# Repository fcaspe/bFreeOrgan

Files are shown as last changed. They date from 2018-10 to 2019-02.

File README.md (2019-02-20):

# bFreeOrgan
### A free Organ Synthesizer based on STM32F4.
**by Franco Caspe**

bFreeOrgan is an open source plattform for Additive Synthesis based on the well-regarded and low-cost Cortex M4 Microcontroller.
As of today, the plattform is used to implement a Synchronous Drawbar Organ Synthesizer that works with the STM32F407 Discovery board.
This project started in 2017, coded in C with ST Microelectronics Standard Peripheral Driver.

### Project state
This project is now IDE agnostic! Is built now with GNU make and arm gcc toolset.

[ARM GCC Toolset website](https://developer.arm.com/open-source/gnu-toolchain/gnu-rm/downloads)

For Flashing the discovery, the makefile uses texane/stlink tool. The latest version that is currently working fine for the STM32F4 Discovery board is 1.3.0.

[Texane's stlink utility](https://github.com/texane/stlink)

This repo currently contains the source and System Workbench project, KiCad project for the Main PCB and some calibration utils.
You can fancy your own drawbar controller (SEE PDF). 
3D Print Case is still pending! But, with a little creativity this project can be built! (see images)

### Building
Just make sure the arm-gcc toolset path is set in the PATH bash's enviroment variable when you run make.

1. Run: make
2. Connect the STM32F4 Discovery Board to the PC.
3. Run: make flash

### See it working!

[bFreeOrgan Prototype No.1](https://www.youtube.com/watch?v=Aql0KdO9ymM&t=1s)
### Some Images

Last Version PCB!
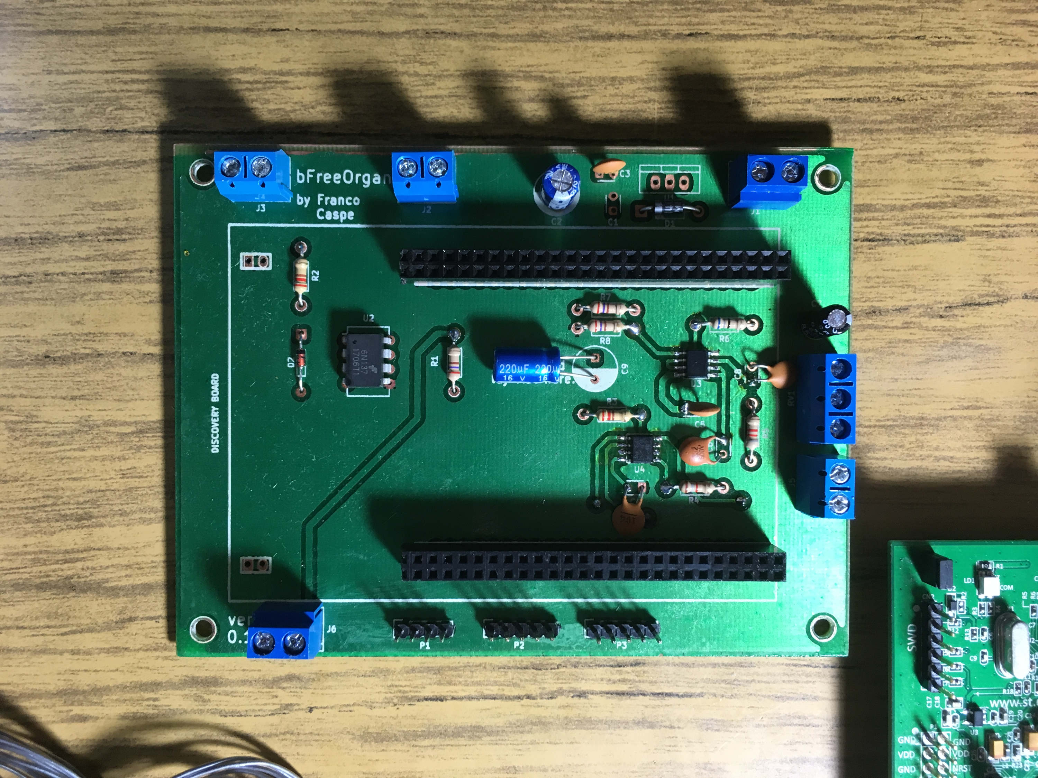
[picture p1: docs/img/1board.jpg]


bFreeOrgan PCB with Discovery board mounted on.
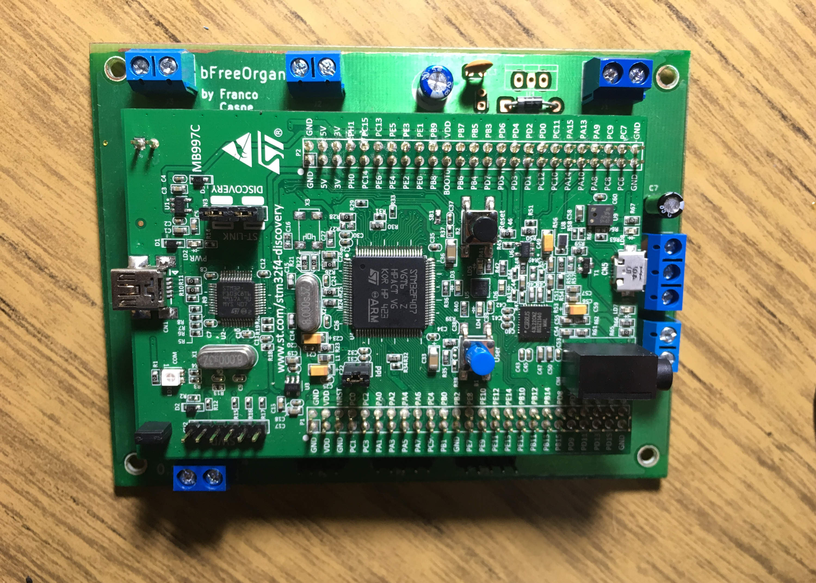
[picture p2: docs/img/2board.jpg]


Front Prototype Case
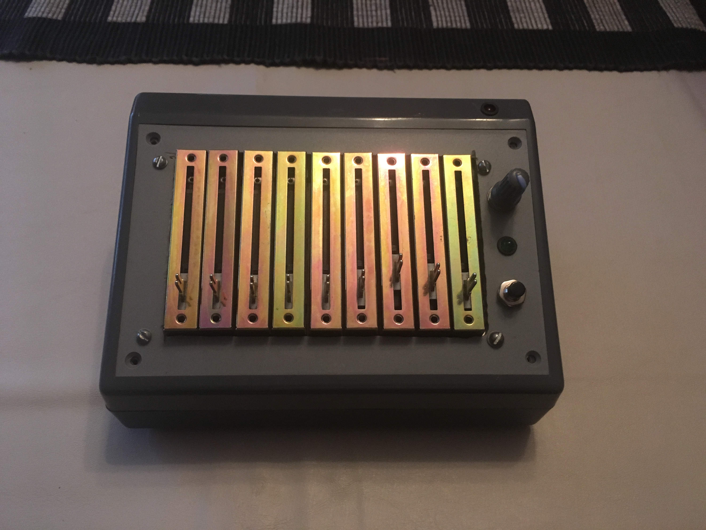
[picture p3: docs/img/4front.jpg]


Rear Prototype Case
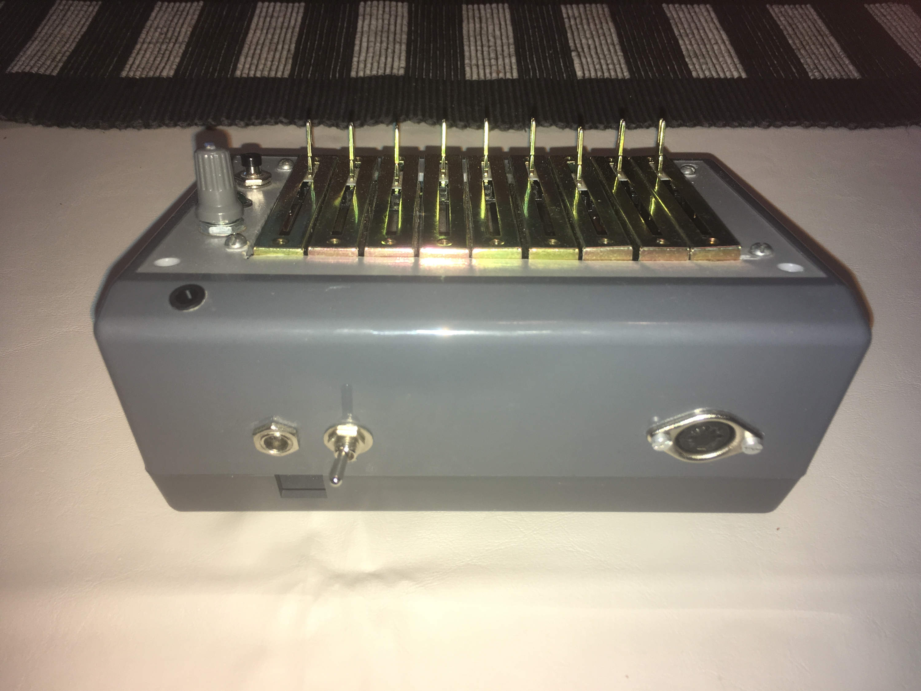
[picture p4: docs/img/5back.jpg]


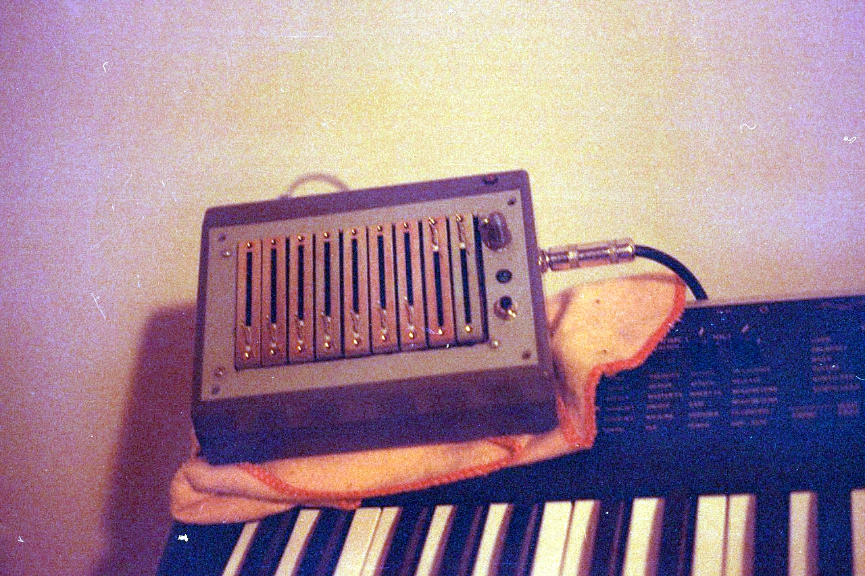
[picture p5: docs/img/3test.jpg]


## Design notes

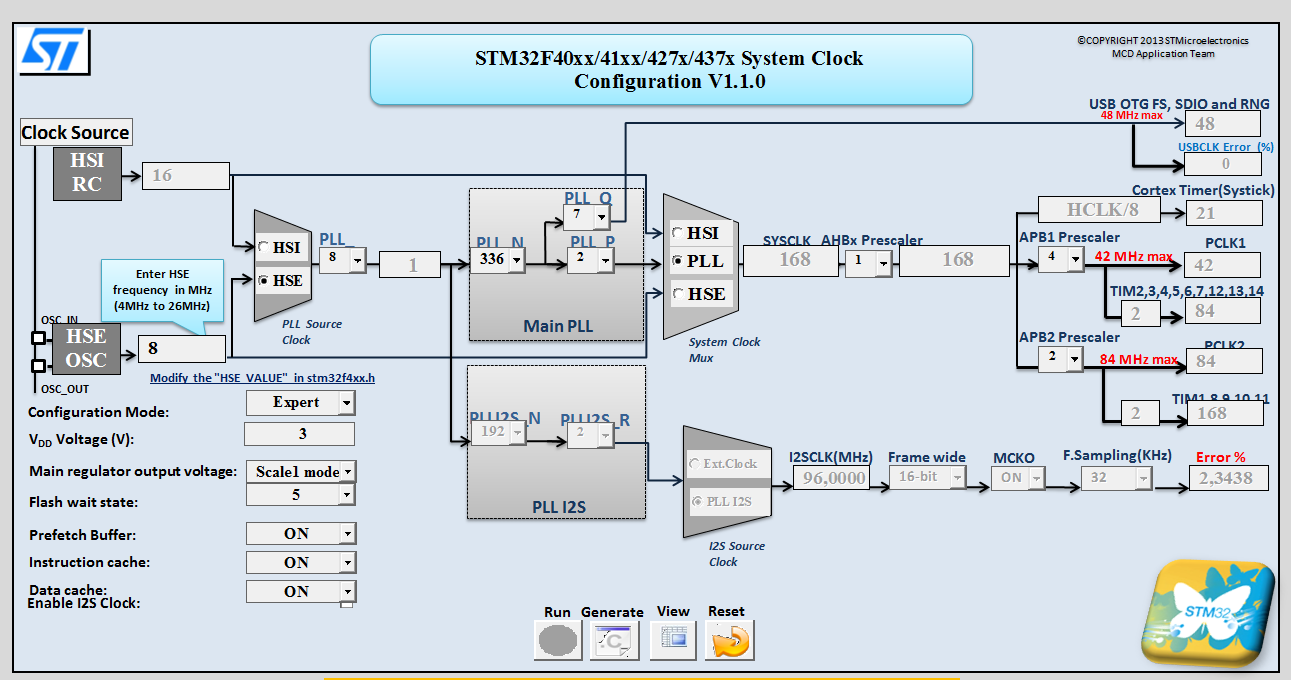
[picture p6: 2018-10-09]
src/src/clock_config.png

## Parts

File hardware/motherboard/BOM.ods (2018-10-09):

Reference | Value | Footprint | Datasheet
JDISCOVERY1 | STM32F4_Discovery_Header | w_conn_misc:stm32f4_discovery_header
J1 | Screw_Terminal_1x02 | Connectors:bornier2
J3 | Screw_Terminal_1x02 | Connectors:bornier2
J2 | 5V Auxiliar | Connectors:bornier2
J5 | Screw_Terminal_1x02 | Connectors:bornier2
J6 | Drawbar Board +3V | Connectors:bornier2
RV1 | 10k | Connectors:bornier3
U1 | 7805 | TO_SOT_Packages_THT:TO-220_Neutral123_Vertical
U2 | 6N137 | Housings_DIP:DIP-8_W7.62mm
U4 | MAX5541 | SMD_Packages:SOIC-8-N
U3 | MC33202 | SMD_Packages:SOIC-8-N
D1 | 1N4007 | Diodes_THT:Diode_DO-41_SOD81_Horizontal_RM10
D2 | 1N4148 | Diodes_THT:Diode_DO-35_SOD27_Horizontal_RM10
R2 | 220 | Resistors_THT:Resistor_Horizontal_RM10mm
R1 | 270 | Resistors_THT:Resistor_Horizontal_RM10mm
R3 | 220 | Resistors_THT:Resistor_Horizontal_RM10mm
R4 | 1.8k | Resistors_THT:Resistor_Horizontal_RM10mm
R5 | 8.2k | Resistors_THT:Resistor_Horizontal_RM10mm
R6 | 68 | Resistors_THT:Resistor_Horizontal_RM10mm
R7 | 270 | Resistors_THT:Resistor_Horizontal_RM10mm
R8 | 270 | Resistors_THT:Resistor_Horizontal_RM10mm
C1 | 330nF | Capacitors_THT:C_Disc_D3_P2.5
C2 | 220uF | Capacitors_THT:C_Radial_D8_L21_P3.8
C6 | 3.3nF | Capacitors_THT:C_Disc_D3_P2.5
C8 | 1nF | Capacitors_THT:C_Disc_D3_P2.5
C3 | 100nF | Capacitors_THT:C_Disc_D3_P2.5
C5 | 100nF | Capacitors_THT:C_Disc_D3_P2.5
C7 | 22uF | Capacitors_THT:C_Radial_D5_L11_P2.5
C4 | 100nF | Capacitors_THT:C_Disc_D3_P2.5
C9 | 220uF | Capacitors_THT:C_Radial_D8_L21_P3.8
P3 | CONN_01X05 | Pin_Headers:Pin_Header_Straight_1x05
P2 | CONN_01X05 | Pin_Headers:Pin_Header_Straight_1x05
P1 | CONN_01X04 | Pin_Headers:Pin_Header_Straight_1x04

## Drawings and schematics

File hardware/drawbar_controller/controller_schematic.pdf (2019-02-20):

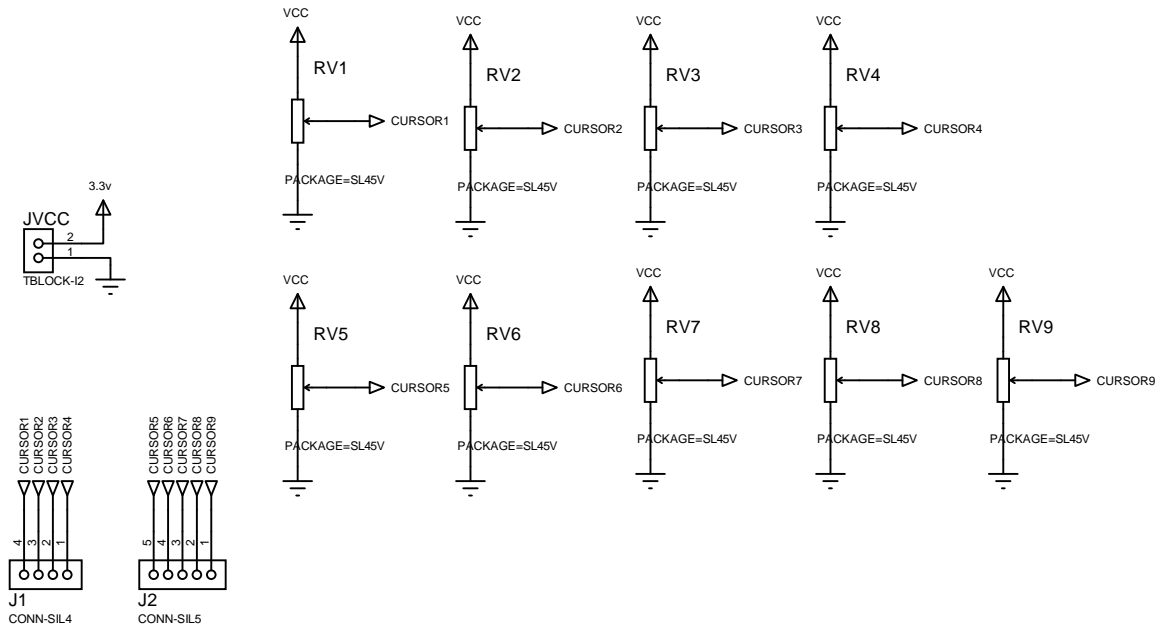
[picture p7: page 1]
PACKAGE=SL45V; VCC; CURSOR1; CURSOR2; CURSOR3; CURSOR4; CURSOR5; CURSOR6; CURSOR7; CURSOR8; CURSOR9; CONN-SIL4; CONN-SIL5; JVCC; TBLOCK-I2

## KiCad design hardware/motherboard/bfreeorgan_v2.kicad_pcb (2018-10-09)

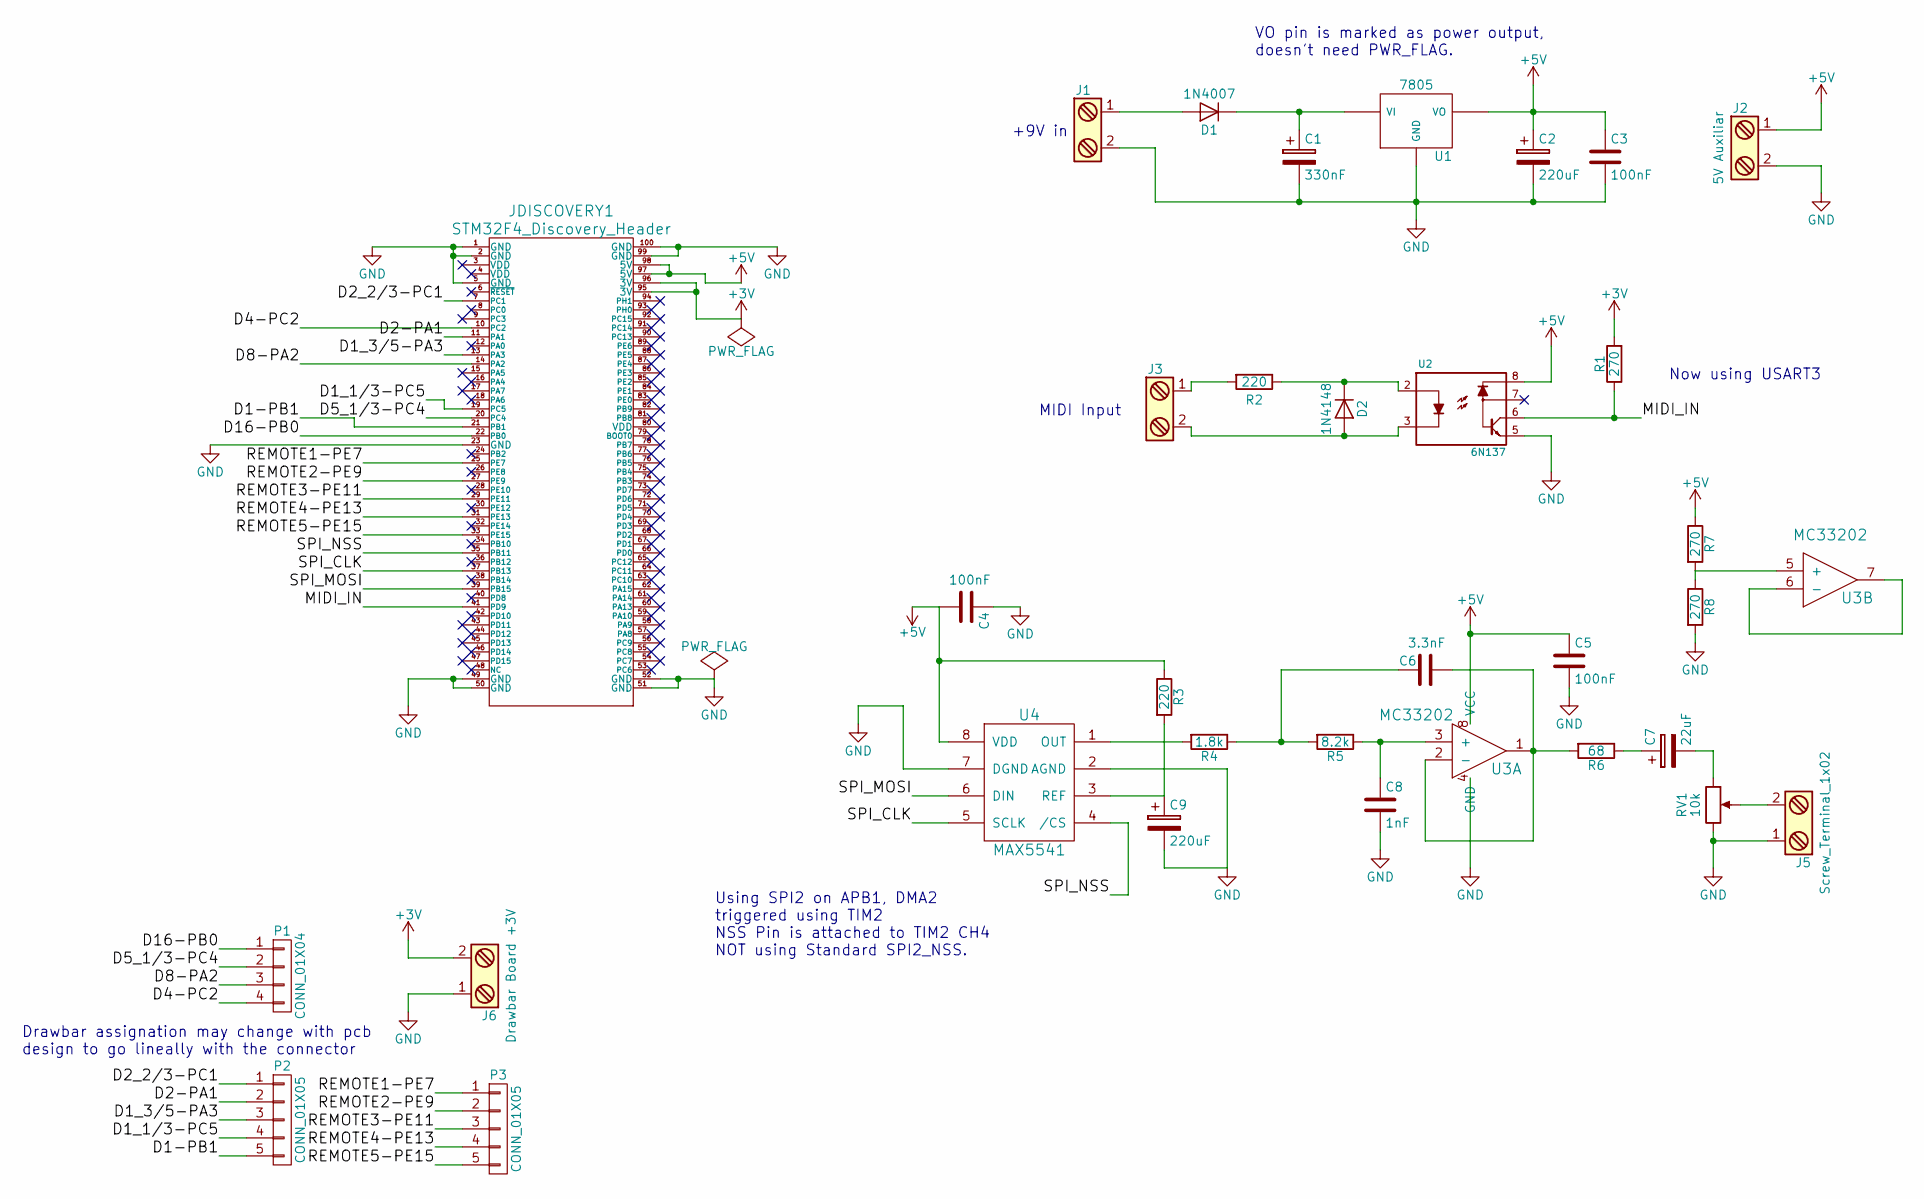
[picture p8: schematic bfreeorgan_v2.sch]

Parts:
C1: 330nF; C_Disc_D3_P2.5
C2, C9: 220uF; C_Radial_D8_L21_P3.8
C3, C4, C5: 100nF; C_Disc_D3_P2.5
C6: 3.3nF; C_Disc_D3_P2.5
C7: 22uF; C_Radial_D5_L11_P2.5
C8: 1nF; C_Disc_D3_P2.5
D1: 1N4007; Diode_DO-41_SOD81_Horizontal_RM10
D2: 1N4148; Diode_DO-35_SOD27_Horizontal_RM10
J1, J3, J5: Screw_Terminal_1x02; bornier2
J2: 5V Auxiliar; bornier2
J6: Drawbar Board +3V; bornier2
JDISCOVERY1: STM32F4_Discovery_Header; stm32f4_discovery_header
P1: CONN_01X04; Pin_Header_Straight_1x04
P2, P3: CONN_01X05; Pin_Header_Straight_1x05
R1, R7, R8: 270; Resistor_Horizontal_RM10mm
R2, R3: 220; Resistor_Horizontal_RM10mm
R4: 1.8k; Resistor_Horizontal_RM10mm
R5: 8.2k; Resistor_Horizontal_RM10mm
R6: 68; Resistor_Horizontal_RM10mm
RV1: 10k; bornier3
U1: 7805; TO-220_Neutral123_Vertical
U2: 6N137; DIP-8_W7.62mm
U3: MC33202; SOIC-8-N
U4: MAX5541; SOIC-8-N

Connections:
+3V: J6.2, JDISCOVERY1.95 (3V), JDISCOVERY1.96 (3V), R1.2; also elsewhere on the board
+5V: C2.1, C3.1, C4.2, C5.1, J2.1, JDISCOVERY1.97 (5V), JDISCOVERY1.98 (5V), R3.1, R7.1, U1.3 (VO), U2.8, U3.8 (VCC), U4.8 (VDD); also elsewhere on the board
/D1-PB1: JDISCOVERY1.21 (PB1), P2.5; also elsewhere on the board
/D1_1/3-PA3: JDISCOVERY1.13 (PA3), P2.3; also elsewhere on the board
/D1_3/5-PA1: JDISCOVERY1.11 (PA1), P2.2; also elsewhere on the board
/D2_2/3-PC1: JDISCOVERY1.7 (PC1), P2.1; also elsewhere on the board
/D4-PC2: JDISCOVERY1.10 (PC2), P1.4; also elsewhere on the board
/D5_1/3-PA2: JDISCOVERY1.14 (PA2), P1.3; also elsewhere on the board
/D16-PB0: JDISCOVERY1.22 (PB0), P1.1; also elsewhere on the board
/DX-PC4: JDISCOVERY1.20 (PC4), P1.2; also elsewhere on the board
/DX-PC5: JDISCOVERY1.19 (PC5), P2.4; also elsewhere on the board
/MIDI_IN: JDISCOVERY1.41 (PD9), R1.1, U2.6; also elsewhere on the board
/REMOTE1: JDISCOVERY1.25 (PE7), P3.1; also elsewhere on the board
/REMOTE2: JDISCOVERY1.27 (PE9), P3.2; also elsewhere on the board
/REMOTE3: JDISCOVERY1.29 (PE11), P3.3; also elsewhere on the board
/REMOTE4: JDISCOVERY1.31 (PE13), P3.4; also elsewhere on the board
/REMOTE5: JDISCOVERY1.33 (PE15), P3.5; also elsewhere on the board
/SPI_CLK: JDISCOVERY1.37 (PB13), U4.5 (SCLK); also elsewhere on the board
/SPI_MOSI: JDISCOVERY1.39 (PB15), U4.6 (DIN); also elsewhere on the board
/SPI_NSS: JDISCOVERY1.35 (PB11), U4.4 (/CS); also elsewhere on the board
GND: C1.2, C2.2, C3.2, C4.1, C5.2, C8.2, C9.2, J1.2, J2.2, J5.1, J6.1, JDISCOVERY1.1 (GND), JDISCOVERY1.2 (GND), JDISCOVERY1.5 (GND), JDISCOVERY1.23 (GND), JDISCOVERY1.49 (GND), JDISCOVERY1.50 (GND), JDISCOVERY1.51 (GND), JDISCOVERY1.52 (GND), JDISCOVERY1.99 (GND), JDISCOVERY1.100 (GND), R8.2, RV1.3, U1.2 (GND), U2.5, U3.4 (GND), U4.2 (AGND), U4.7 (DGND); also elsewhere on the board
unnamed: C1.1, D1.1 (K), U1.1 (VI)
unnamed: C6.1, R6.2, U3.1, U3.2 (-)
unnamed: C6.2, R4.1, R5.2
unnamed: C7.1, R6.1
unnamed: C7.2, RV1.1
unnamed: C8.1, R5.1, U3.3 (+)
unnamed: C9.1, R3.2, U4.3 (REF)
unnamed: D1.2 (A), J1.1
unnamed: D2.1 (K), R2.1, U2.2
unnamed: D2.2 (A), J3.2, U2.3
unnamed: J3.1, R2.2
unnamed: J5.2, RV1.2
unnamed: R4.2, U4.1 (OUT)
unnamed: R7.2, R8.1, U3.5 (+)
unnamed: U3.6 (-), U3.7

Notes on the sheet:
+9V in
Using SPI2 on APB1, DMA2 triggered using TIM2 NSS Pin is attached to TIM2 CH4 NOT using Standard SPI2_NSS.
Now using USART3
MIDI Input
VO pin is marked as power output, doesn't need PWR_FLAG.
Drawbar assignation may change with pcb design to go lineally with the connector

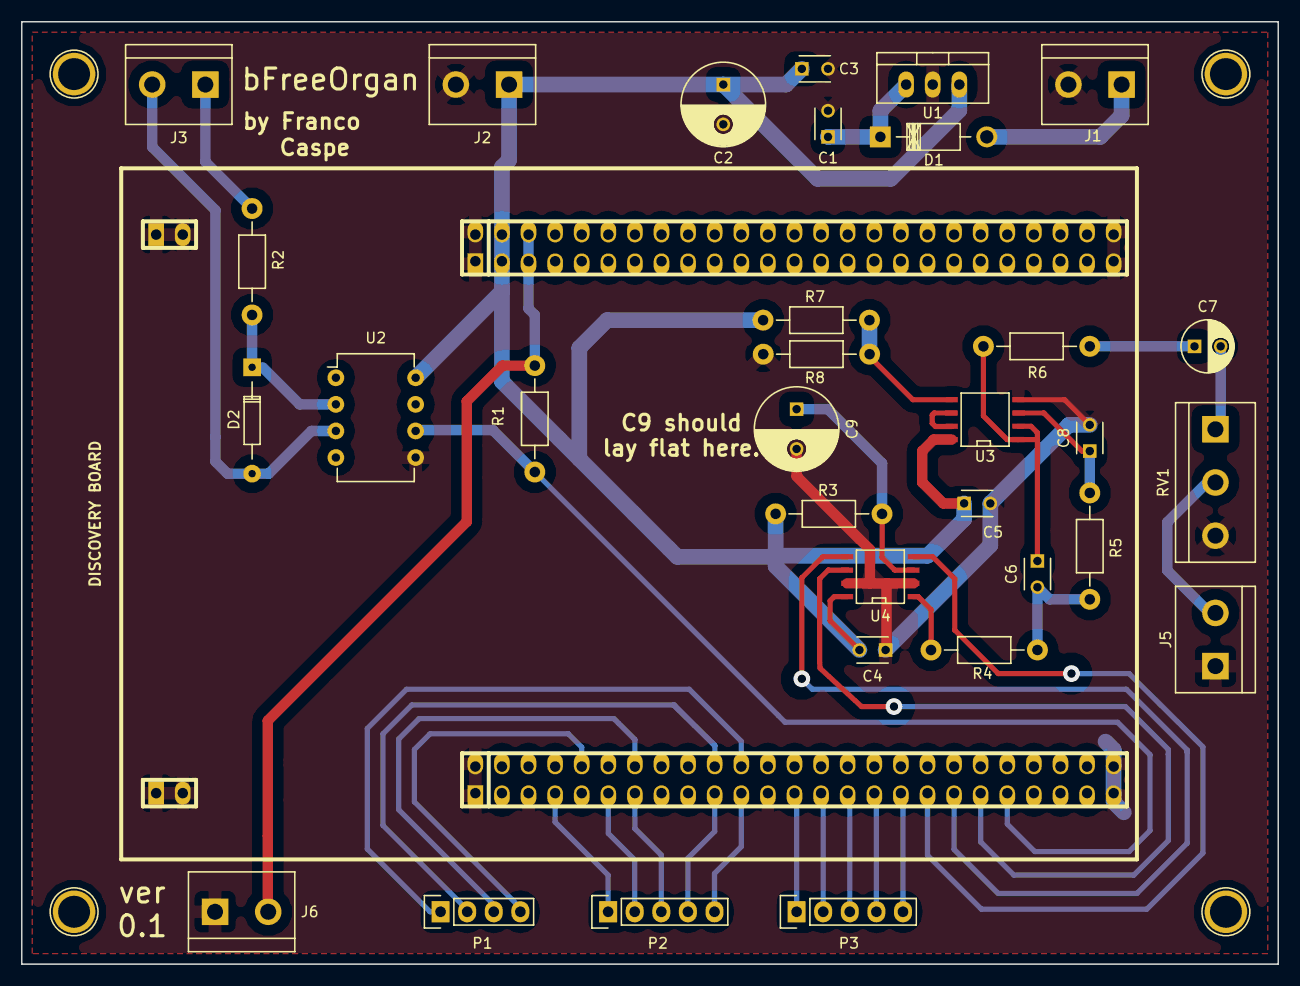
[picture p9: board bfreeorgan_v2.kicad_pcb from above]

Board: 2 copper layers, 120.0 x 90.0 mm, 33 parts (0 on the bottom side), 36 nets.

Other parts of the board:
DISCOVERY BOARD: STM32F4_Discovery_Header; stm32f4_discovery_header

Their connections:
+3V: DISCOVERY BOARD.95, DISCOVERY BOARD.96; also elsewhere on the board
+5V: DISCOVERY BOARD.97, DISCOVERY BOARD.98; also elsewhere on the board
/D1-PB1: DISCOVERY BOARD.21; also elsewhere on the board
/D1_1/3-PA3: DISCOVERY BOARD.13; also elsewhere on the board
/D1_3/5-PA1: DISCOVERY BOARD.11; also elsewhere on the board
/D2_2/3-PC1: DISCOVERY BOARD.7; also elsewhere on the board
/D4-PC2: DISCOVERY BOARD.10; also elsewhere on the board
/D5_1/3-PA2: DISCOVERY BOARD.14; also elsewhere on the board
/D16-PB0: DISCOVERY BOARD.22; also elsewhere on the board
/DX-PC4: DISCOVERY BOARD.20; also elsewhere on the board
/DX-PC5: DISCOVERY BOARD.19; also elsewhere on the board
/MIDI_IN: DISCOVERY BOARD.41; also elsewhere on the board
/REMOTE1: DISCOVERY BOARD.25; also elsewhere on the board
/REMOTE2: DISCOVERY BOARD.27; also elsewhere on the board
/REMOTE3: DISCOVERY BOARD.29; also elsewhere on the board
/REMOTE4: DISCOVERY BOARD.31; also elsewhere on the board
/REMOTE5: DISCOVERY BOARD.33; also elsewhere on the board
/SPI_CLK: DISCOVERY BOARD.37; also elsewhere on the board
/SPI_MOSI: DISCOVERY BOARD.39; also elsewhere on the board
/SPI_NSS: DISCOVERY BOARD.35; also elsewhere on the board
GND: DISCOVERY BOARD.1, DISCOVERY BOARD.2, DISCOVERY BOARD.5, DISCOVERY BOARD.23, DISCOVERY BOARD.49, DISCOVERY BOARD.50, DISCOVERY BOARD.51, DISCOVERY BOARD.52, DISCOVERY BOARD.99, DISCOVERY BOARD.100; also elsewhere on the board

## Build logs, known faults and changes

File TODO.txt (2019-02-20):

TODO temporary list

- Add Quick Start Guide to docs.
- Update Kicad PCB
- 3D Print Case

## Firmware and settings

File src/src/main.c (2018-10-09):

#include "stm32f4xx.h"
#include "includes.h"


/* VARIABLES GLOBALES DEL SISTEMA */

uint16_t sys_DACbuffer1[32]; //Buffer de una muestra, leido por el DAC.
uint16_t sys_DACbuffer0[32]; //Buffer de una muestra, leido por el DAC.
uint16_t *sys_DACcurrent;	 //Pointer to point to the buffer that's being filled with data.
uint16_t sys_sampleSent; 	 //Contador de numero de muestras enviadas
FlagStatus sys_bufferCrash;  //Indica que en algun momento no se enviaron correctamente los datos al DAC.
FlagStatus sys_bufferPending;
char sys_TXbuff[TX_BUFFOUT];

int main(void)
{
	/* Startup Sequence. */
	boot_periph();

	synth_init();
	synth_FSM();

	for(;;);
}

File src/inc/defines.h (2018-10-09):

#define ADC1_DR_ADDRESS    ((uint32_t)0x4001204C)

/* LEDS ---------------------------------------------------------*/


#define LED_VERDE GPIO_Pin_12
#define LED_NARANJA GPIO_Pin_13
#define LED_ROJO GPIO_Pin_14
#define LED_AZUL GPIO_Pin_15


/* DEFINES DATALOGGER -------------------------------- ----------- */
#define TX_BUFFOUT 16

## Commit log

2018-01-29 Added Source and Project files.
    [trankasynth Debug.cfg]
2018-10-09 New v2: Added KiCad PCB supporting external DAC. Updated firmware. Added calibration utils.
    [BOM.ods, bfreeorgan Debug.cfg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]
2019-02-20 Moved project to GNU Make. Added Drawbar controller schematic.
    [BOM.ods, bfreeorgan Debug.cfg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]
